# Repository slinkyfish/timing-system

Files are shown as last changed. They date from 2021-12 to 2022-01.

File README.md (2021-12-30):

# timing-system
Components for a micromouse and line follower contest timing system.

Initial development will be related to a drag race timer. 

The contest is described here: https://ukmars.org/contests/drag-race/

And the rules are here: https://ukmars.org/contests/contest-rules/drag-race/

The `legacy` folder contains design files for the existing equipment used in UK contests at Birmingham City University and originally designed by Tony Wilcox.

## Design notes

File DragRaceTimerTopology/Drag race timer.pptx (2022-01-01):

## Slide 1

Drag race timer.pptx

Drag race timer - System block diagram

RATS PC

Power

Signals

Control box

End gantry 1

Lane 1 timer &
6 character display

Start LEDs

Lane 2 timer &
6 character display

Start LEDs

End gantry 2

End gate board

Start gantry 2

End gate board

LED

LED

Start gantry 1

Start gate board

Crossed start LED

Crossed start LED

Start gate board

LED

LED

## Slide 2

Gate processor board components & interfaces

Option to power beam LED from battery when not using gantry

switch

Timer /counter board

Beam state
Seen/Not Seen
High when beam broken or not seen

switch

Micro

Power on LED

5V
Gnd

Beam detector

Beam LED and current limiting resistor

Sensitivity adjuster

Beam not seen indicator LED and current limiting resistor
= Start crossed indicator

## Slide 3

Timer /counter board components and interfaces

12 V DC supply
or battery

2 Push buttons

LED driver 1

LED driver 2

LED driver 3

Gate sensor board 1

Beam state
Seen/Not Seen
High when beam broken or not seen

5V
Gnd

On/off switch

5V reg

Timer Micro processor

Mode selection switches

High - trigger the start light sequence

Gate sensor board 2

Beam state
Seen/Not Seen
High when beam broken or not seen

5V
Gnd

High - All lights out. start timer

Start lights board – This could be incorporated onto the timer/counter board or on a separate board on the end gantry

Serial time data

Arm/ Start

Gnd

5V

Control board

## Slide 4

Control board components & interfaces

ARM
START
RESET
OTHER

Push buttons

Mode switches

Timer Counter board 1

Serial data 1

State display
LEDS

Arm/Start 1

Arm/Start 1

Timer Counter board 2

5V

5V

Serial data 2

Gnd

Micro processor

LEDS

Timer 1 connected

Arm/Start 2

Timer 2 connected

RATS connected

5V

Gnd

USB data link

From 5v supply inputs

RATS PC

Board gets 5v power from either timer/counter board or the USB cable whichever is connected

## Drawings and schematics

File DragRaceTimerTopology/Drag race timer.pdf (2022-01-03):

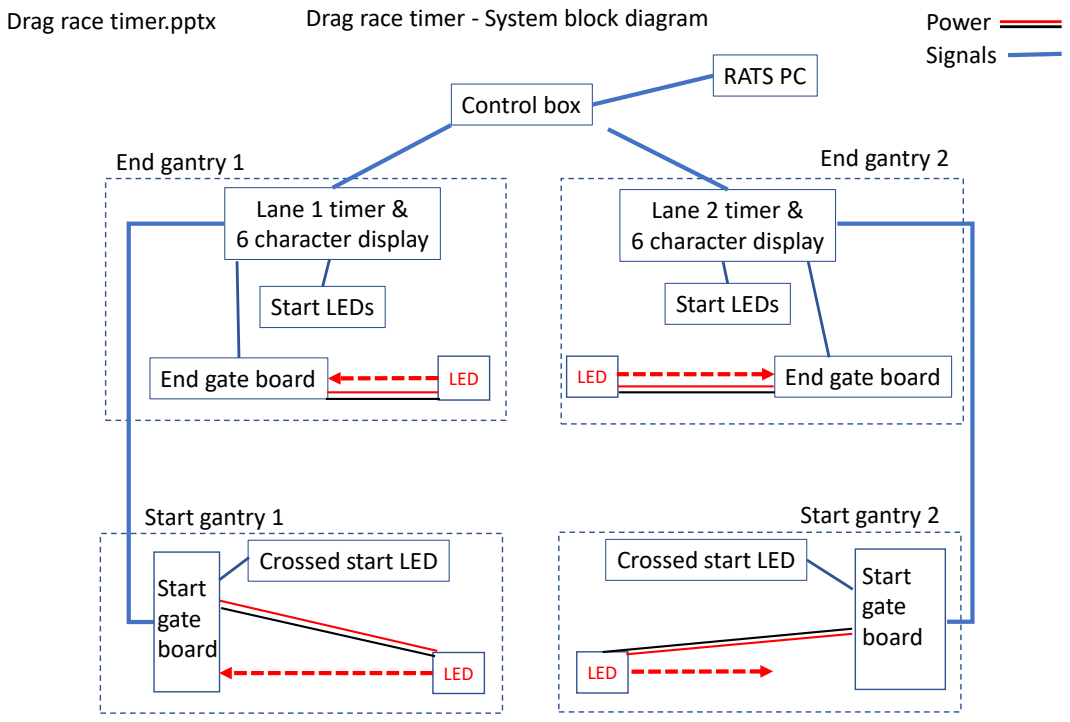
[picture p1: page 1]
Lane 1 timer & 6 character display; Control box; End gate board; LED; Lane 2 timer & 6 character display; Crossed start LED; RATS PC; End gantry 1; End gantry 2; Start gantry 1; Start gantry 2; Power Signals; Start LEDs; Start gate board

Drag race timer.pptx

Drag race timer - System block diagram

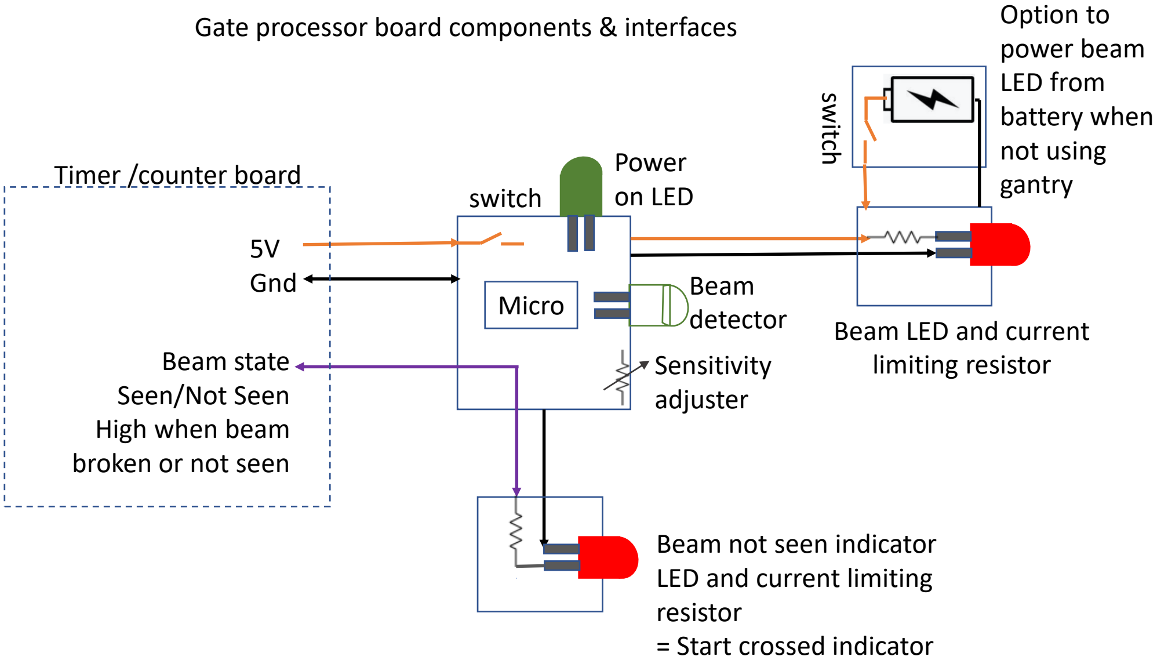
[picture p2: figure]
5V Gnd; Beam state Seen/Not Seen High when beam broken or not seen; Beam not seen indicator LED and current limiting resistor = Start crossed indicator; Beam LED and current limiting resistor; Power; switch; on LED; Timer /counter board; Beam detector; Sensitivity adjuster; Option to power beam LED from battery when not using gantry; Micro

Gate processor board components & interfaces

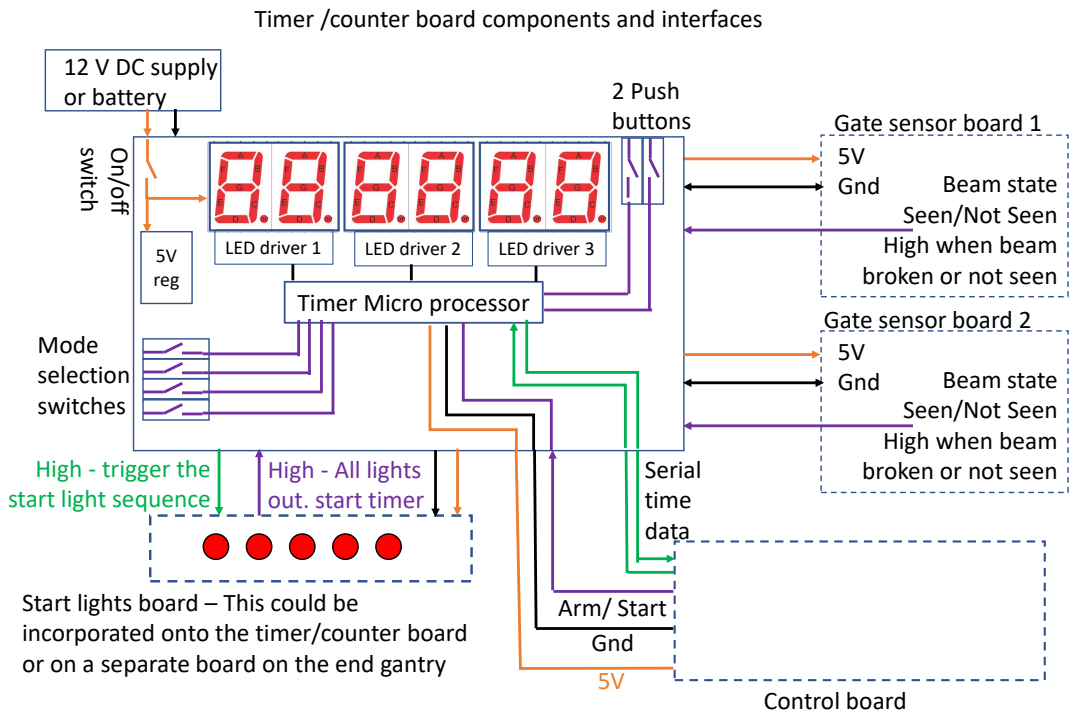
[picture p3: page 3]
Gnd; Beam state; LED driver 1; LED driver 2; LED driver 3; 5V reg; Mode selection switches; Control board; Arm/ Start; 2 Push buttons; Serial time data

Timer /counter board components and interfaces

12 V DC supply
or battery switch On/off

Gate sensor board 1
Seen/Not Seen
High when beam
broken or not seen
Gate sensor board 2

Timer Micro processor

High - trigger the
start light sequence

High - All lights
out. start timer

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

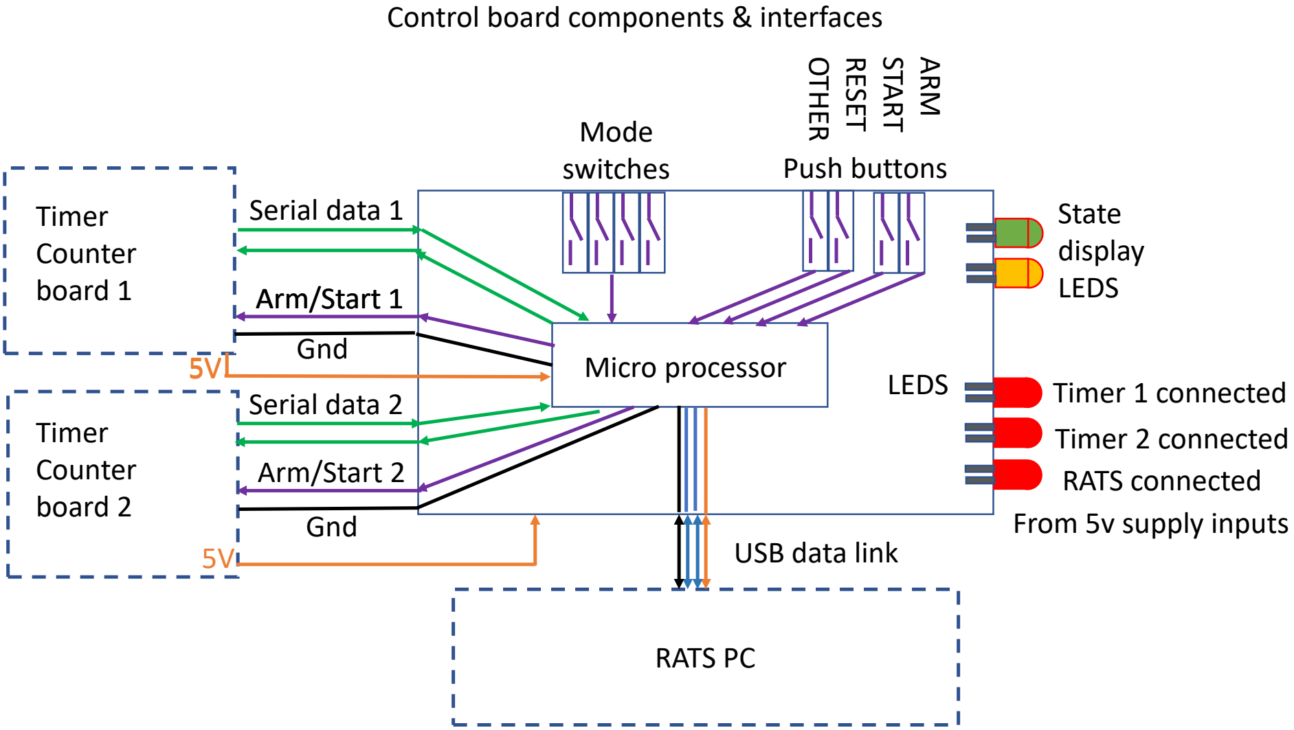
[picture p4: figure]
Control board components & interfaces; Timer Counter board 1; Timer Counter board 2; Serial data 1; Serial data 2; Arm/Start 1; Arm/Start 2; Push buttons; RATS PC; USB data link; Micro processor Gnd; Gnd; LEDS; Mode switches; RATS connected; Timer 1 connected Timer 2 connected; OTHER; RESET; START; ARM; State display LEDS; From 5v supply inputs

Board gets 5v power from either timer/counter board or the USB cable whichever is connected

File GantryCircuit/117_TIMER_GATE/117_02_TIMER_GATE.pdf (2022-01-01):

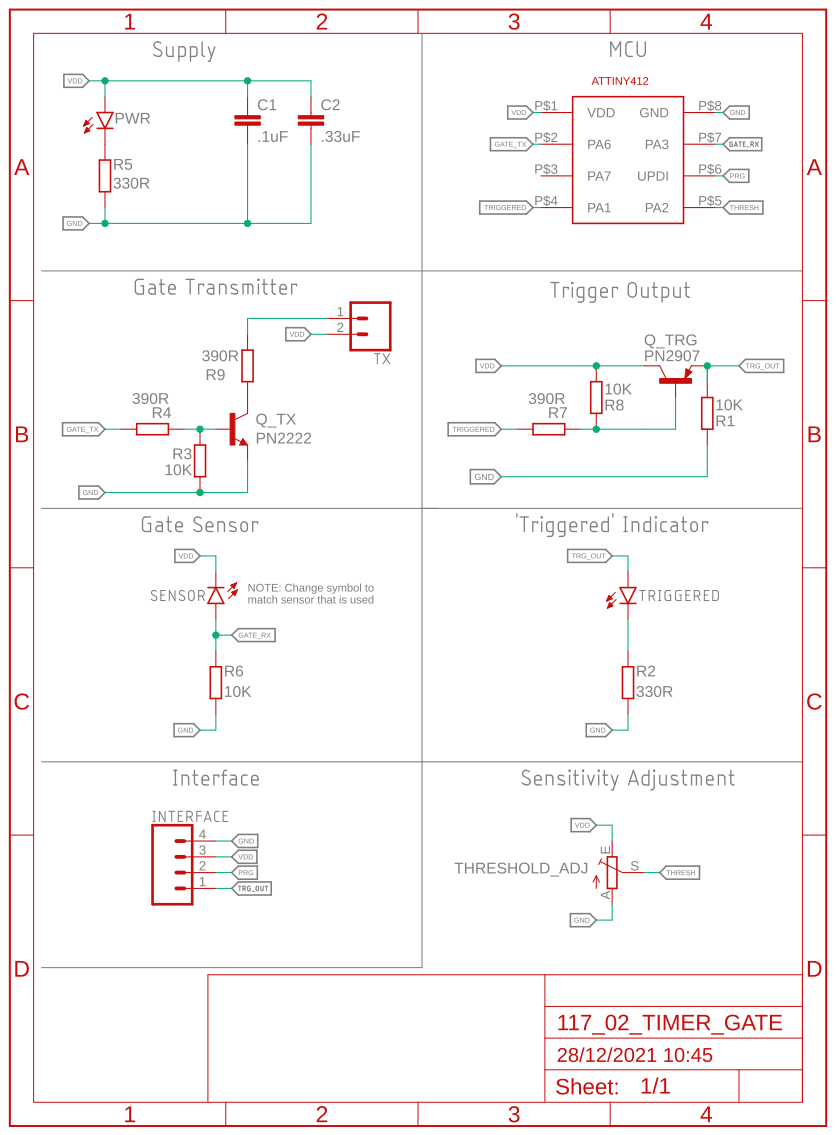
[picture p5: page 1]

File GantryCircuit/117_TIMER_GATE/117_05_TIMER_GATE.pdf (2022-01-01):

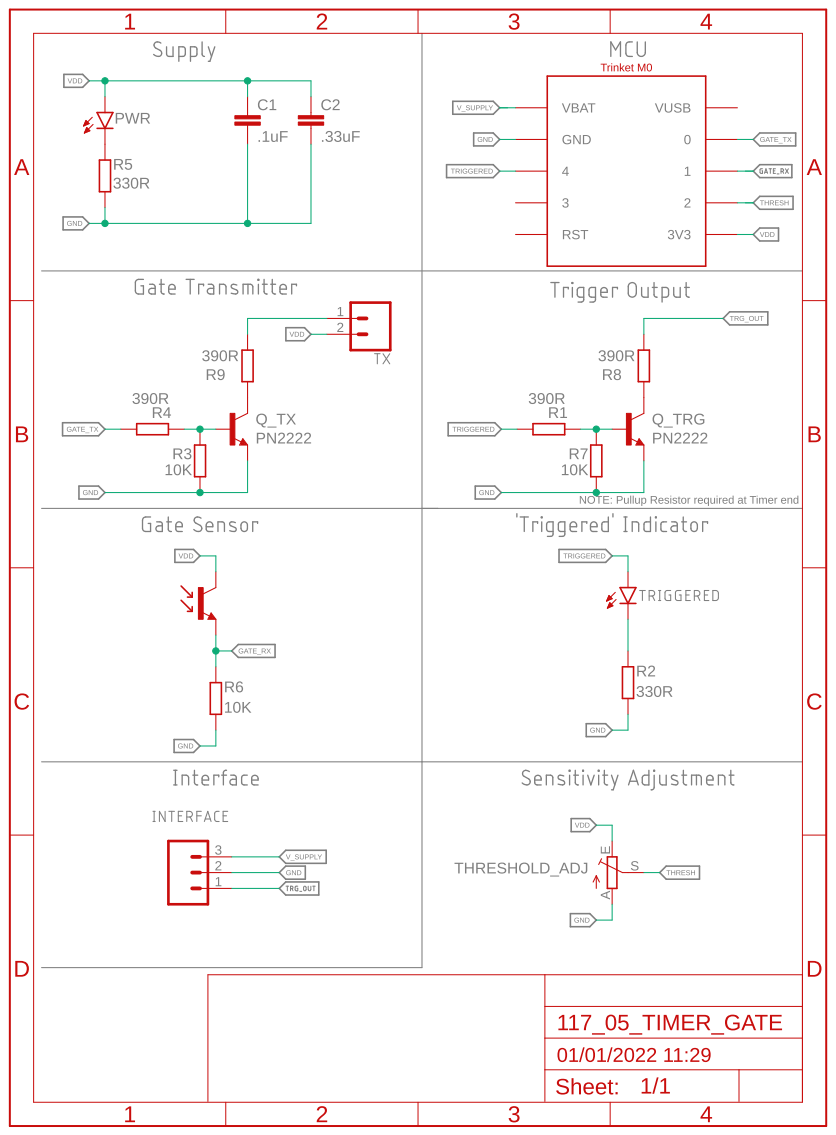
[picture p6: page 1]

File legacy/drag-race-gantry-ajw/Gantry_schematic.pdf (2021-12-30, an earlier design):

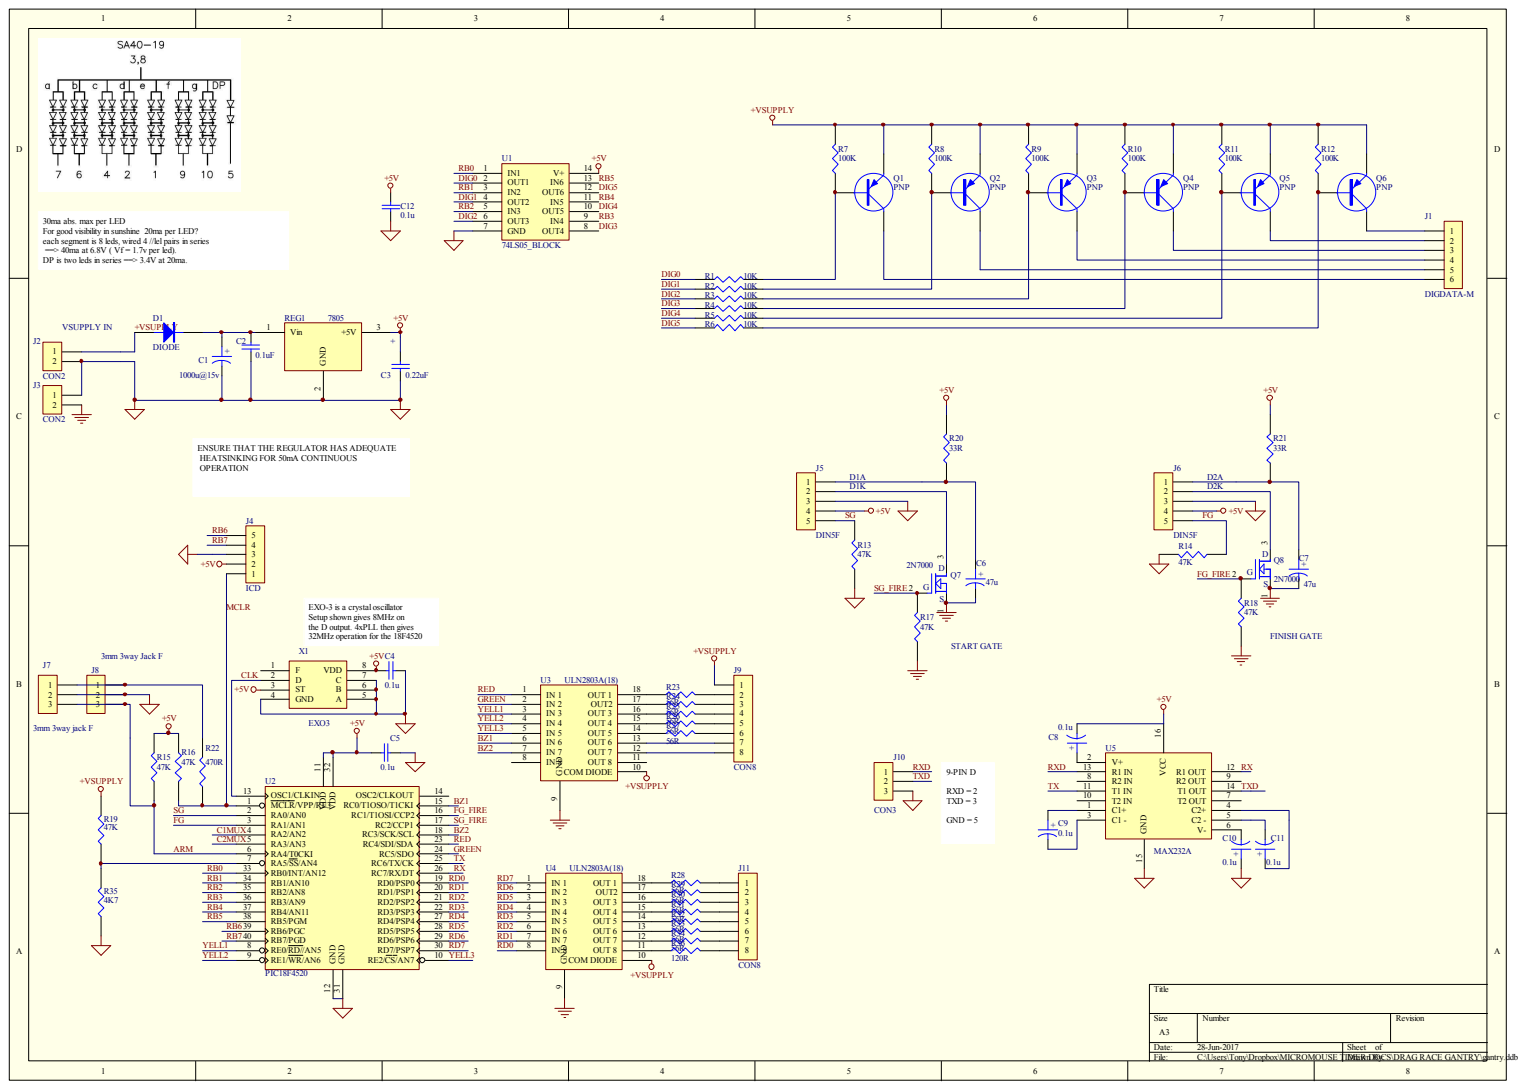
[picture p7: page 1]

30ma abs. max per LED
For good visibility in sunshine 20ma per LED?
each segment is 8 leds, wired 4 //lel pairs in series
==> 40ma at 6.8V ( Vf = 1.7v per led).
DP is two leds in series ==> 3.4V at 20ma.

ENSURE THAT THE REGULATOR HAS ADEQUATE
HEATSINKING FOR 50mA CONTINUOUS
OPERATION

EXO-3 is a crystal oscillator
Setup shown gives 8MHz on
the D output. 4xPLL then gives
32MHz operation for the 18F4520

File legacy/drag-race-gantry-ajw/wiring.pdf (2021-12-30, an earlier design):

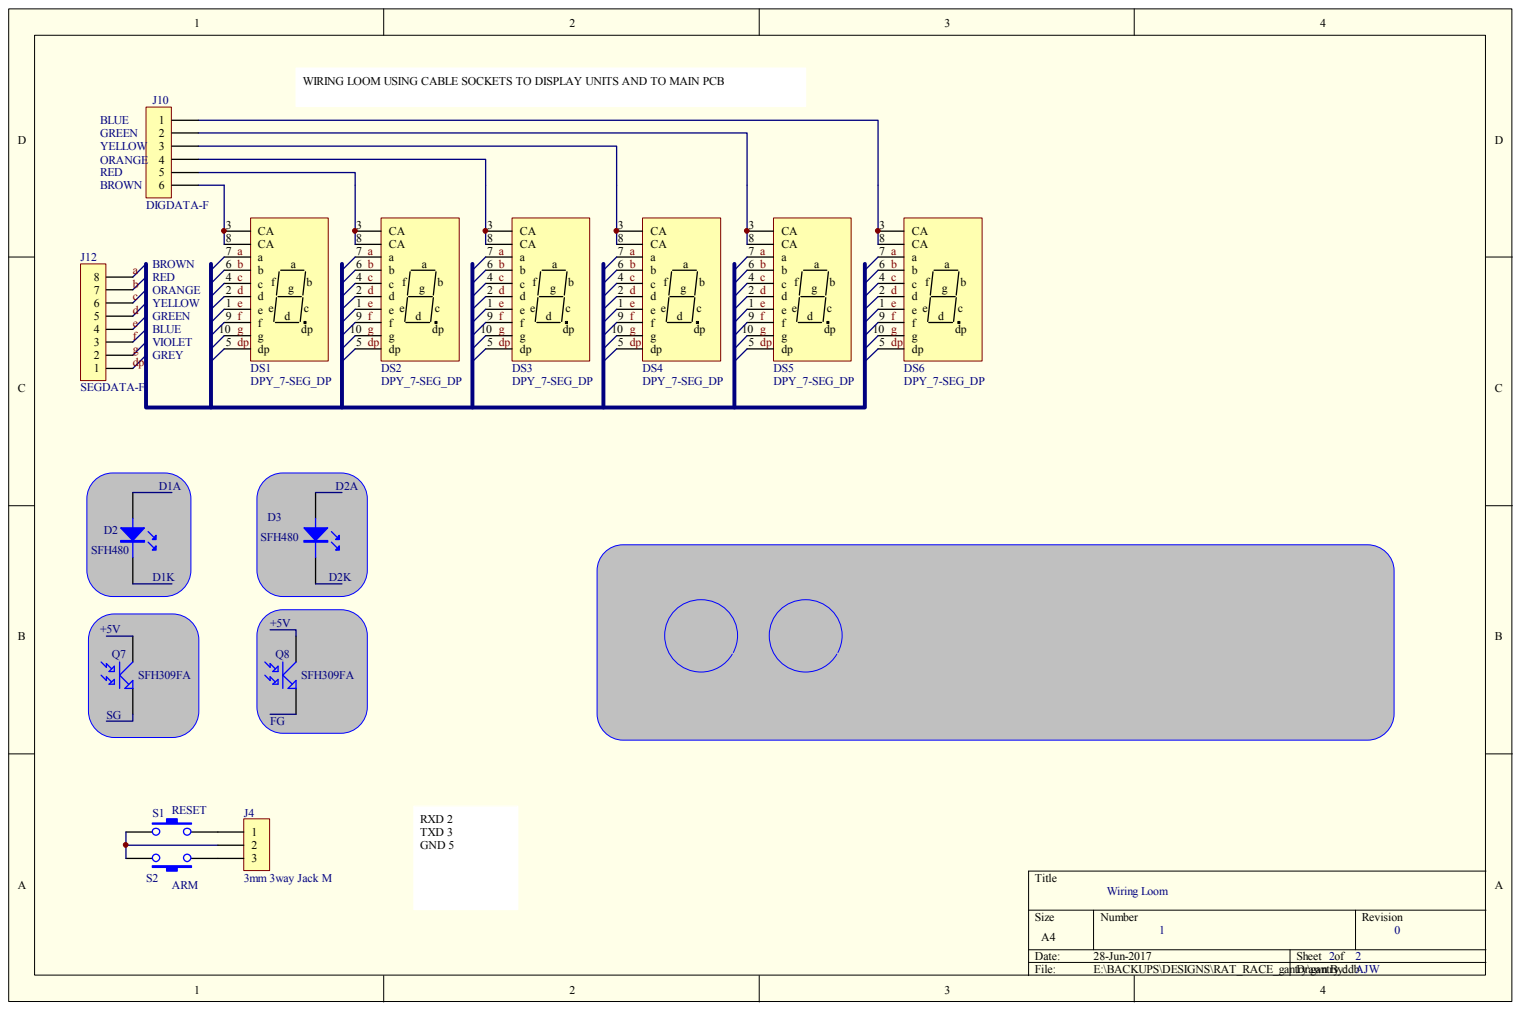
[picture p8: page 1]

WIRING LOOM USING CABLE SOCKETS TO DISPLAY UNITS AND TO MAIN PCB

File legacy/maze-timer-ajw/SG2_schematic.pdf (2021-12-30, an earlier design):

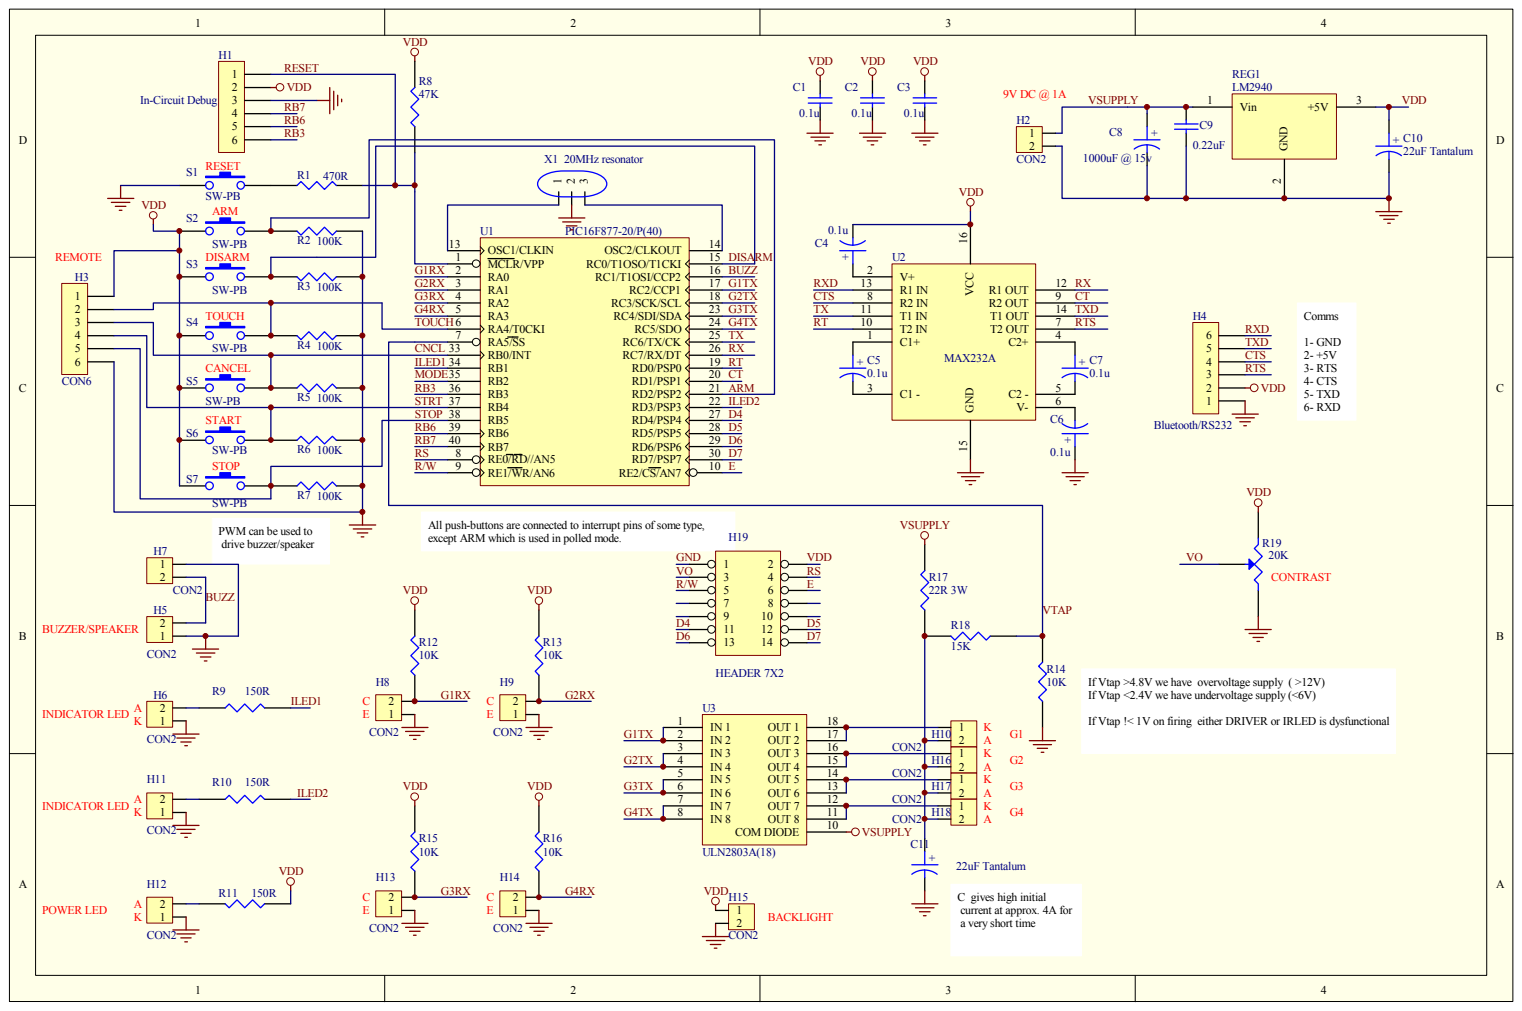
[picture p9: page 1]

PWM can be used to
drive buzzer/speaker

All push-buttons are connected to interrupt pins of some type,
except ARM which is used in polled mode.

If Vtap >4.8V we have overvoltage supply ( >12V)
If Vtap <2.4V we have undervoltage supply (<6V)

If Vtap !< 1V on firing either DRIVER or IRLED is dysfunctional

C gives high initial
current at approx. 4A for
a very short time

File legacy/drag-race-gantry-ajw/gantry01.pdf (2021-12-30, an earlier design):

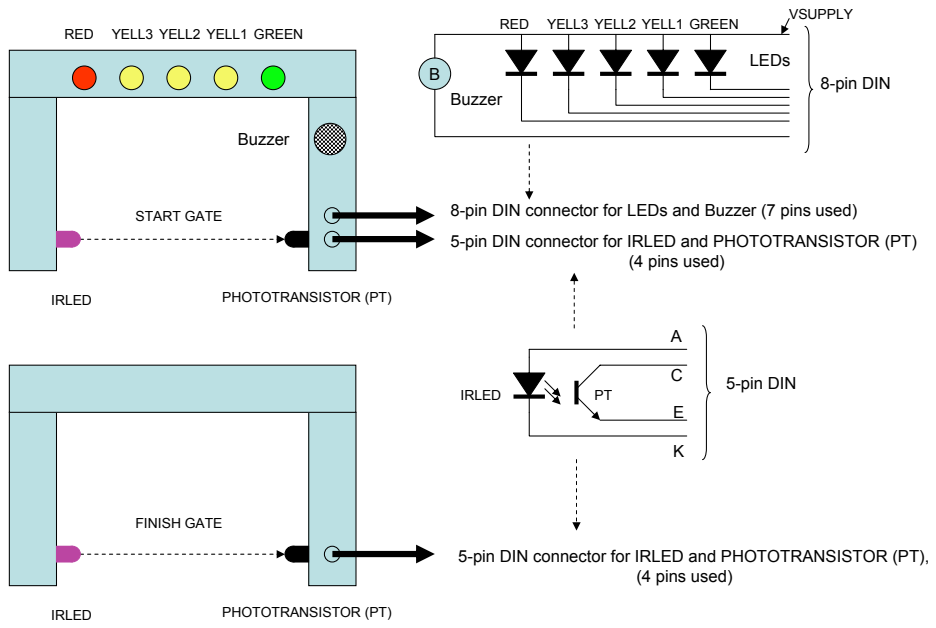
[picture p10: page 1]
(4 pins used); Buzzer; LEDs; 8-pin DIN; 5-pin DIN; RED YELL3 YELL2 YELL1 GREEN; VSUPPLY; IRLED; PHOTOTRANSISTOR (PT); START GATE; FINISH GATE

8-pin DIN connector for LEDs and Buzzer (7 pins used)
5-pin DIN connector for IRLED and PHOTOTRANSISTOR (PT)

5-pin DIN connector for IRLED and PHOTOTRANSISTOR (PT),

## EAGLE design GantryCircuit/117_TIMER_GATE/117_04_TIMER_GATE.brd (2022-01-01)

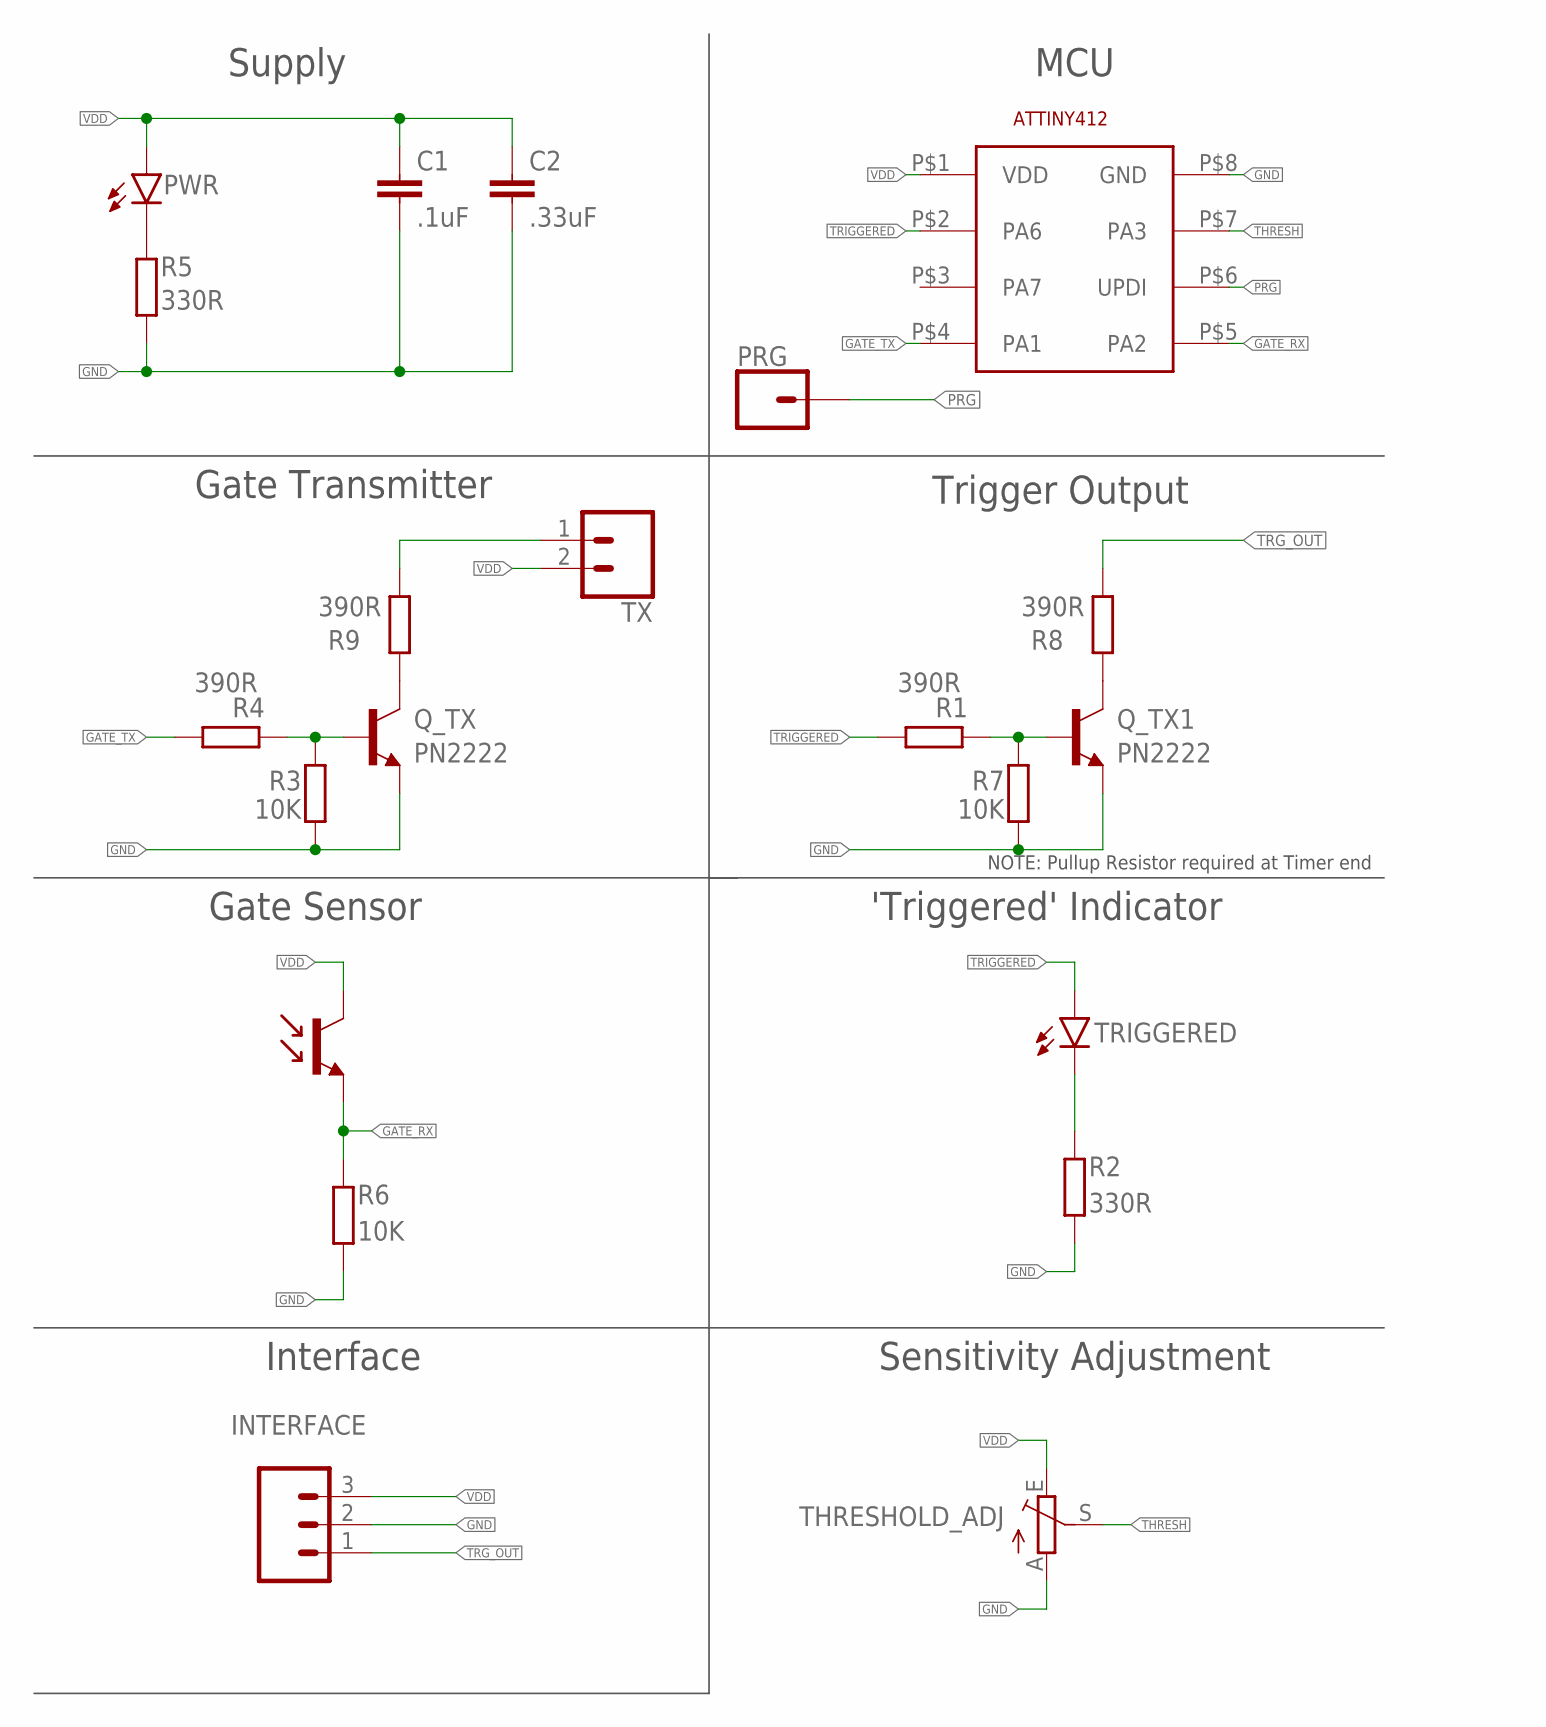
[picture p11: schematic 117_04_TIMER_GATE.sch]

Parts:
C1: .1uF; C0805K
C2: .33uF; C0805K
INTERFACE: CONN_03LONGPADS; 1X03_LONGPADS
PRG: CONN_01PTH_LONGPAD; 1X01_LONGPAD
PWR: LEDSML0805; SML0805
Q_TX, Q_TX1: PN2222; TO92-EBC
R1, R4, R8, R9: 390R; M0805
R2, R5: 330R; M0805
R3, R6, R7: 10K; M0805
THRESHOLD_ADJ: TRIM_EU-S64W; S64W
TRIGGERED: LED5MM; LED_5MM
TX: CONN_02PTH3; 1X02_LONGPADS
U$1: ATTINY412
U$2: PHOTOTRANSISTOR; LED_5MM

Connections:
GATE_RX: R6.2, U$1.P$5 (PA2), U$2.K (E)
GATE_TX: R4.2, U$1.P$4 (PA1)
GND: C1.2, C2.2, INTERFACE.2, Q_TX.E, Q_TX1.E, R2.1, R3.2, R5.1, R6.1, R7.2, THRESHOLD_ADJ.A, U$1.P$8 (GND)
unnamed: PWR.C, R5.2
unnamed: R9.1, TX.1
unnamed: Q_TX1.B, R1.1, R7.1
unnamed: Q_TX.B, R3.1, R4.1
unnamed: Q_TX.C, R9.2
unnamed: Q_TX1.C, R8.2
unnamed: R2.2, TRIGGERED.K (C)
PRG: PRG.1, U$1.P$6 (UPDI)
THRESH: THRESHOLD_ADJ.S, U$1.P$7 (PA3)
TRG_OUT: INTERFACE.1, R8.1
TRIGGERED: R1.2, TRIGGERED.A, U$1.P$2 (PA6)
VDD: C1.1, C2.1, INTERFACE.3, PWR.A, THRESHOLD_ADJ.E, TX.2, U$1.P$1 (VDD), U$2.A (C)

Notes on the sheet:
Gate Sensor
'Triggered' Indicator
Sensitivity Adjustment
Supply
MCU
Gate Transmitter
Interface
Trigger Output
NOTE: Pullup Resistor required at Timer end

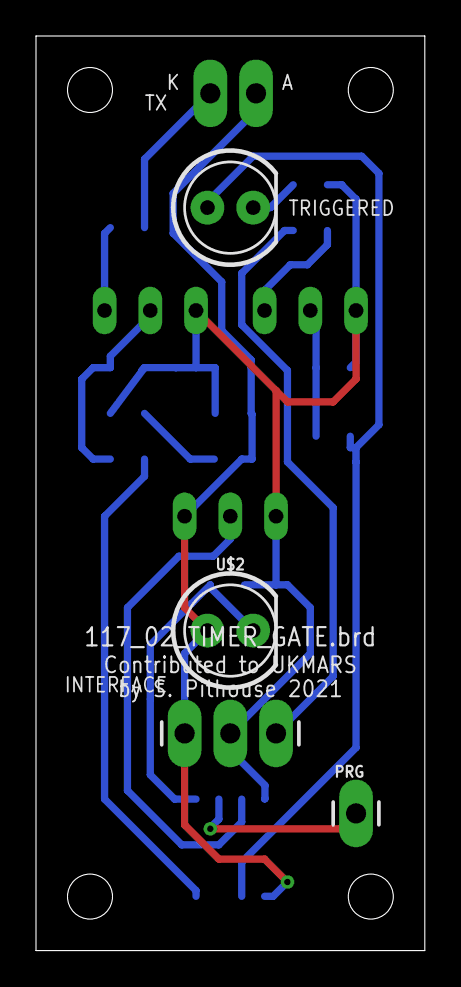
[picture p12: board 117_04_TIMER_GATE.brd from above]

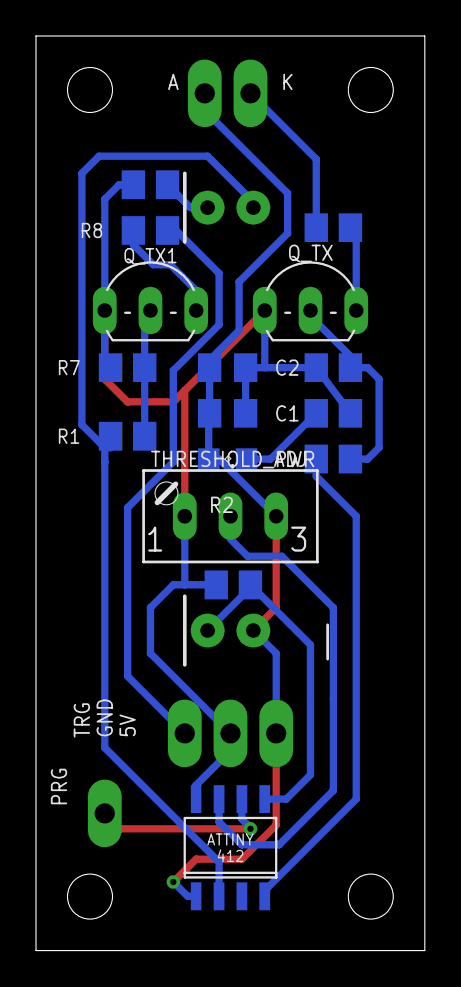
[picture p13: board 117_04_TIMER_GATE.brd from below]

Board: 2 copper layers, 21.6 x 50.8 mm, 21 parts (16 on the bottom side), 15 nets.

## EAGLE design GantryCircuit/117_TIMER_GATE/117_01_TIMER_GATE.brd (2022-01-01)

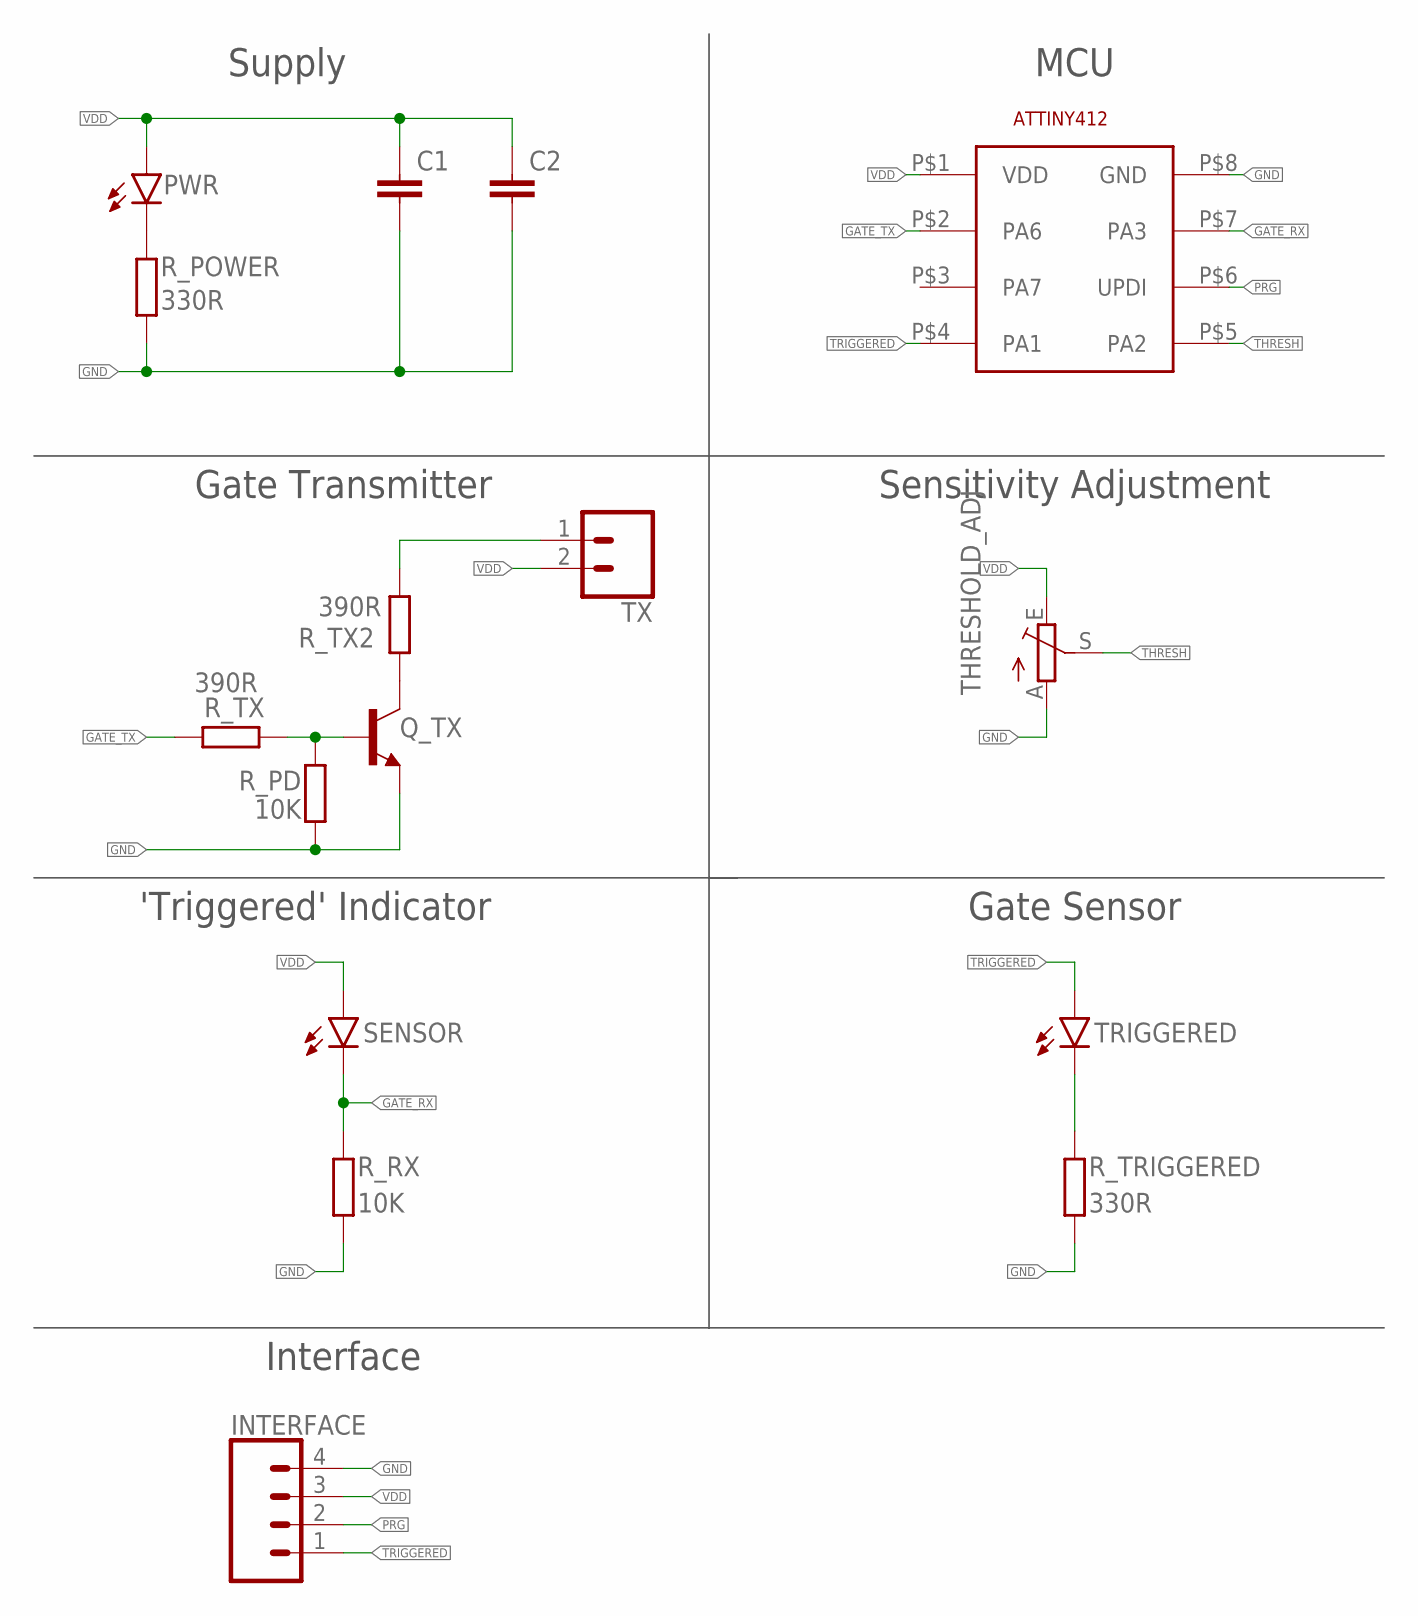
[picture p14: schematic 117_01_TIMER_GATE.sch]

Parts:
C1, C2: C-EUC0805K; C0805K
INTERFACE: CONN_04LONGPADS; 1X04_LONGPADS
PWR: LEDSML0805; SML0805
Q_TX: 2N2222-NPN-TO92-EBC; TO92-EBC
R_PD: 10K; M0805
R_POWER: 330R; M0805
R_RX: 10K; M0805
R_TRIGGERED: 330R; M0805
R_TX, R_TX2: 390R; M0805
SENSOR: LED5MM; LED_5MM
THRESHOLD_ADJ: TRIM_EU-S64W; S64W
TRIGGERED: LED5MM; LED_5MM
TX: CONN_02PTH3; 1X02_LONGPADS
U$1: ATTINY412

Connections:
GATE_RX: R_RX.2, SENSOR.K (C), U$1.P$7 (PA3)
GATE_TX: R_TX.2, U$1.P$2 (PA6)
GND: C1.2, C2.2, INTERFACE.4, Q_TX.E, R_PD.2, R_POWER.1, R_RX.1, R_TRIGGERED.1, THRESHOLD_ADJ.A, U$1.P$8 (GND)
unnamed: PWR.C, R_POWER.2
unnamed: R_TX2.1, TX.1
unnamed: Q_TX.B, R_PD.1, R_TX.1
unnamed: Q_TX.C, R_TX2.2
unnamed: R_TRIGGERED.2, TRIGGERED.K (C)
PRG: INTERFACE.2, U$1.P$6 (UPDI)
THRESH: THRESHOLD_ADJ.S, U$1.P$5 (PA2)
TRIGGERED: INTERFACE.1, TRIGGERED.A, U$1.P$4 (PA1)
VDD: C1.1, C2.1, INTERFACE.3, PWR.A, SENSOR.A, THRESHOLD_ADJ.E, TX.2, U$1.P$1 (VDD)

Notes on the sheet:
Gate Sensor
'Triggered' Indicator
Sensitivity Adjustment
Supply
MCU
Gate Transmitter
Interface

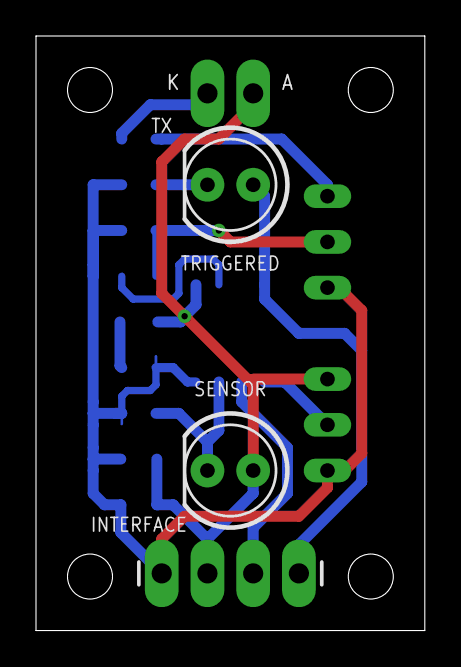
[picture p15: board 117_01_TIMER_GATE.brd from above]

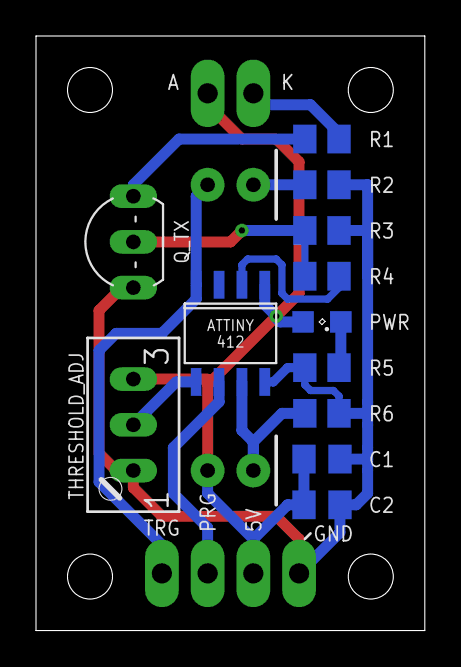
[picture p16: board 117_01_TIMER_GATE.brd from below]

Board: 2 copper layers, 21.6 x 33.0 mm, 16 parts (12 on the bottom side), 12 nets.

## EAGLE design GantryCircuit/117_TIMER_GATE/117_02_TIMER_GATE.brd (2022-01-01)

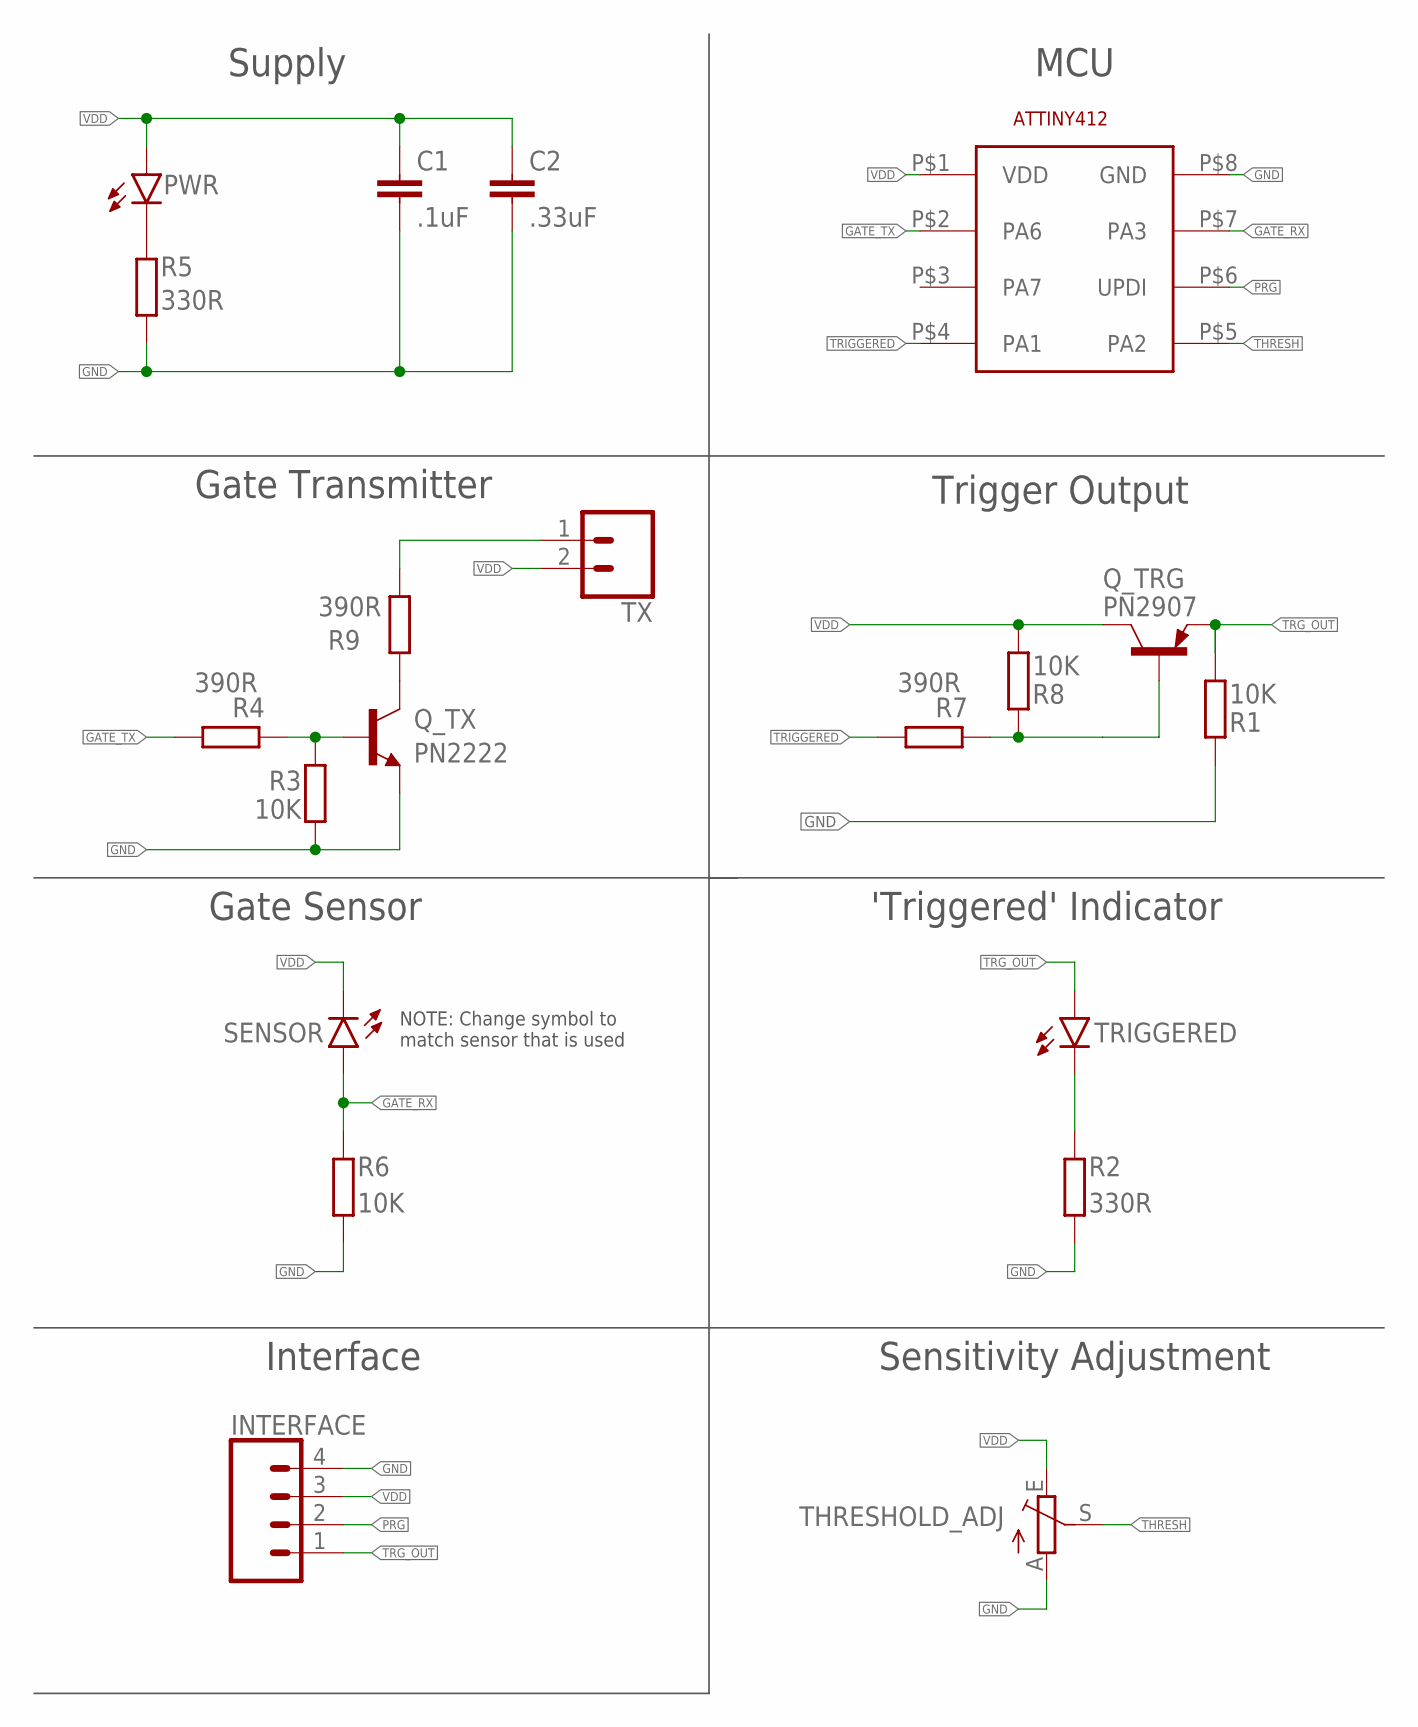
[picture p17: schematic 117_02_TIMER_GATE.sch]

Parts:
C1: .1uF; C0805K
C2: .33uF; C0805K
INTERFACE: CONN_04LONGPADS; 1X04_LONGPADS
PWR: LEDSML0805; SML0805
Q_TRG: PN2907; TO92-CBE
Q_TX: PN2222; TO92-EBC
R1, R3, R6, R8: 10K; M0805
R2, R5: 330R; M0805
R4, R7, R9: 390R; M0805
SENSOR: LED5MM; LED_5MM
THRESHOLD_ADJ: TRIM_EU-S64W; S64W
TRIGGERED: LED5MM; LED_5MM
TX: CONN_02PTH3; 1X02_LONGPADS
U$1: ATTINY412

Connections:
GATE_RX: R6.2, SENSOR.A, U$1.P$7 (PA3)
GATE_TX: R4.2, U$1.P$2 (PA6)
GND: C1.2, C2.2, INTERFACE.4, Q_TX.E, R1.1, R2.1, R3.2, R5.1, R6.1, THRESHOLD_ADJ.A, U$1.P$8 (GND)
unnamed: PWR.C, R5.2
unnamed: R9.1, TX.1
unnamed: Q_TX.B, R3.1, R4.1
unnamed: Q_TX.C, R9.2
unnamed: R2.2, TRIGGERED.K (C)
PRG: INTERFACE.2, U$1.P$6 (UPDI)
THRESH: THRESHOLD_ADJ.S, U$1.P$5 (PA2)
TRG_BASE: Q_TRG.B, R7.1, R8.1
TRG_OUT: INTERFACE.1, Q_TRG.E, R1.2, TRIGGERED.A
TRIGGERED: R7.2, U$1.P$4 (PA1)
VDD: C1.1, C2.1, INTERFACE.3, PWR.A, Q_TRG.C, R8.2, SENSOR.K (C), THRESHOLD_ADJ.E, TX.2, U$1.P$1 (VDD)

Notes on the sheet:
Gate Sensor
'Triggered' Indicator
Sensitivity Adjustment
Supply
MCU
Gate Transmitter
Interface
Trigger Output
NOTE: Change symbol to match sensor that is used

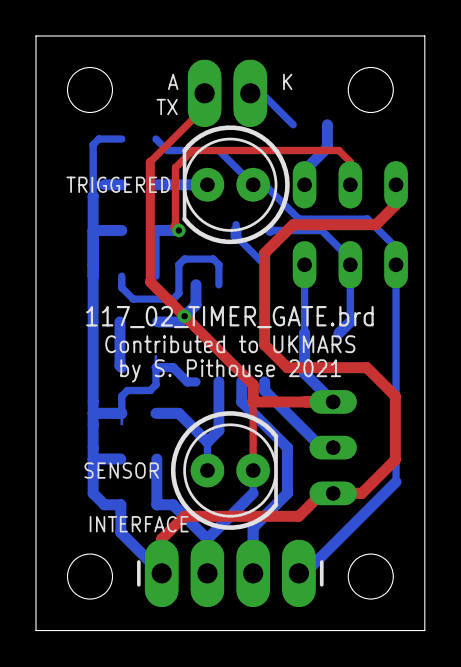
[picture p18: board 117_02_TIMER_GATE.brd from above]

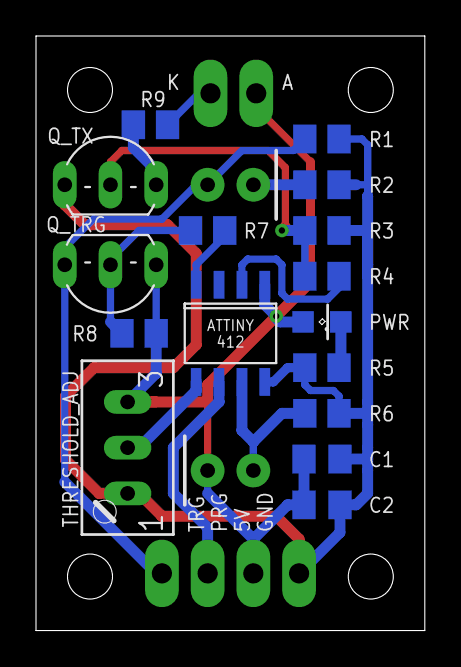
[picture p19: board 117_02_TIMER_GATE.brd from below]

Board: 2 copper layers, 21.6 x 33.0 mm, 20 parts (16 on the bottom side), 14 nets.

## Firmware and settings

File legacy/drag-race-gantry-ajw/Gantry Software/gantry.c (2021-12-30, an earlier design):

// AJW 28/06/07 Gantry timer
// 19/6/07 Added comms at 115200
//
// 19/06/07 added startgate: comparators used.


#include <p18f4520.h>
#include "gantry.h"
#include <timers.h>
#include <usart.h>

#pragma config OSC=HSPLL,PWRT=ON,WDT=OFF,BOREN=OFF,MCLRE=ON,PBADEN=OFF
#pragma config CCP2MX=PORTC,STVREN=ON,LVP=OFF,XINST=OFF,DEBUG=ON

typedef struct {
  unsigned char val0;
  unsigned char val1;
  unsigned char val2;
  unsigned char val3;
  unsigned char val4;
  unsigned char val5;
}  display_buffer ;

static display_buffer dbuf;
static unsigned char TIMER = FALSE, state = 0, SGTRIG = FALSE, FGTRIG = FALSE, FALSE_START = FALSE;
const char seg7[] = {zero, one, two, three, four, five, six, seven, eight, nine, blank};

static unsigned int secs = 0, millisecs = 0, timeout = 0, beeptimer = 0;

/********************* INTERRUPT initialisation ****************************/
void ISR_HI(void);
void ISR_LO(void);
void init_interrupts(void);
void init_cmp(void);
void refresh_display(void);
void update_time(void);
void init_ports(void);
void fsm(void);
void zero_time(void);
void beep(unsigned int);
/*-----------------------------------------------------------------------*/
/* This bit is to initialise the interrupt vectors
/*-----------------------------------------------------------------------*/
#pragma code high_vector_section=0x8  // goto absolute code section
void high_vector(void) {
  _asm GOTO ISR_HI _endasm
}

#pragma code low_vector_section=0x18  // goto absolute code section
void low_vector(void) {
  _asm GOTO ISR_LO _endasm
}

#pragma code   // return to normal code section

/*********************   INTERRUPT routines    ****************************/

/*-----------------------------------------------------------------------*/
/* High level interrupt routine  */
/*-----------------------------------------------------------------------*/
#pragma interrupt ISR_HI
void ISR_HI(void) {
  static unsigned char lastCOUT1 = 0, lastCOUT2 = 0, currentCOUT1 = 0, currentCOUT2 = 0, intcount = 0, dspcount = 0;

  if (PIR1bits.TMR1IF & PIE1bits.TMR1IE) {  // timer 1 is master 1ms timer
    PIR1bits.TMR1IF = 0;
    WriteTimer1(T1CONST);

    SGTX = FGTX = 1; //irleds on
    // use clock/display update as the IRLED setup time
    update_time();
    if (TIMER) {
      if (millisecs++ >= 999) {
        millisecs = 0;
        if (secs++ >= 999) {
          secs = 0;
        }
      }
    }
    if (dspcount++ > 1) {
      dspcount = 0;
      refresh_display();
    }
    // Read Start Gate comparator and set/clear flag
    if (SGRX) {
      SGTRIG = TRUE;  // SG = Start Gate
    } else {
      SGTRIG = FALSE;
    }
    // Read Finish Gate comparator and set/clear flag
    if (FGRX) {
      FGTRIG = TRUE;  // FG = Finish Gate
    } else {
      FGTRIG = FALSE;
    }
    SGTX = FGTX = 0; 	//irleds off
    if (timeout > 0) {
      timeout --;  // countdown
    }
    fsm();				// do state machine
    if (beeptimer > 0) {
      beeptimer --;
      BUZZ1 = TRUE;
    } else {
      BUZZ1 = FALSE;
    }
  }
}
/*-----------------------------------------------------------------------*/
/* low priority interrupt routine  */
/*-----------------------------------------------------------------------*/
#pragma interruptlow ISR_LO
void
ISR_LO(void) {

}

/*********************      MAIN     ****************************/




void main(void) {


  unsigned  int i = 0;

  init_ports();
  init_interrupts();
  init_cmp();
  state = 0;
  WriteTimer1(T1CONST);
  OpenTimer1(TIMER_INT_ON &
             T1_16BIT_RW &
             T1_SOURCE_INT &
             T1_PS_1_1 &
             T1_OSC1EN_OFF &
             T1_SYNC_EXT_OFF);

  OpenUSART(USART_TX_INT_OFF  &
            USART_RX_INT_OFF  &
            USART_ASYNCH_MODE &
            USART_EIGHT_BIT   &
            USART_CONT_RX &
            USART_BRGH_HIGH, 51); //38400 from 32MHz

  while (1) {

  }
}

void init_interrupts(void) {
  /* Enable interrupt priority */
  RCONbits.IPEN = 1;

  /* SET timer1 INTERRUPT PRIORITY and enable*/
  IPR1bits.TMR1IP = 1;
  PIE1bits.TMR1IE = 1;
  INTCONbits.GIEH = 1;
  INTCONbits.GIEL = 1;
}

void init_cmp(void) {
  ADCON1 = 10;
  CMCON = 0x06; // only mode with common CVREF
  CVRCON = 12; // SET TO 2.5V
  CVRCONbits.CVREN = 1;  // comparator on
  CVRCONbits.CVROE = 0;  //
  CVRCONbits.CVRR = 1;
  CVRCONbits.CVRSS = 0;
}

void refresh_display(void) {
  static unsigned char dignum = 0;

  switch (dignum) {
    case 0:
      digsel = dig0;
      dignum ++;
      digdata = seg7[dbuf.val0];
      dp = 0;
      break;
    case 1:
      digsel = dig1;
      dignum ++;
      digdata = seg7[dbuf.val1];
      dp = 0;
      break;
    case 2:
      digsel = dig2;
      dignum ++;
      digdata = seg7[dbuf.val2];
      dp = 0;
      break;
    case 3:
      digsel = dig3;
      dignum ++;
      digdata = seg7[dbuf.val3];
      dp = 1;
      break;
    case 4:
      digsel = dig4;
      dignum ++;
      digdata = seg7[dbuf.val4];
      dp = 0;
      break;
    case 5:
      digsel = dig5;
      dignum = 0;
      //digdata = seg7[dbuf.val5];
      if (FALSE_START) {
        digdata = 0x71;  // F for false
      } else {
        digdata = blank;
      }
      dp = 0;

      break;
  }
}

void update_time(void) {
  dbuf.val0 = millisecs % 10;
  dbuf.val1 = (millisecs / 10) % 10;
  dbuf.val2 = millisecs / 100;
  dbuf.val3 = secs % 10;
  dbuf.val4 = (secs / 10) % 10;
  dbuf.val5 = secs / 100;
}

void zero_time(void) {
  millisecs = 0;
  secs = 0;
}

void init_ports(void) {
  TRISB = 0xc0; 			// bottom 5 outputs  for digit select
  LATB = 0;				// all segments off
  TRISD = 0; 			// all outputs  for segment select i.e. data
  LATD = 0x3f;			// all digits off
  TRISA = 0xff;          // all inputs

  TRISCbits.TRISC3 = 0;	// BUZZ2
  BUZZ2 = 0;
  TRISCbits.TRISC2 = 0;	// SGTX
  SGTX = 0;
  TRISCbits.TRISC1 = 0;	// FGTX
  FGTX = 0;
  TRISCbits.TRISC0 = 0;	// BUZZ1
  BUZZ1 = 0;
  TRISCbits.TRISC5 = 0;	// GREEN led
  GREEN = 0;
  TRISCbits.TRISC4 = 0;	// RED led
  RED = 0;
  TRISEbits.TRISE0 = 0;	// YELL1
  YELL1 = 0;
  TRISEbits.TRISE1 = 0;	// YELL2
  YELL1 = 0;
  TRISEbits.TRISE2 = 0;	// YELL3
  YELL1 = 0;
}

void fsm(void) {
  switch (state) {
    case 0:
      YELL3 = YELL2 = YELL1 = RED = GREEN = FALSE;

      if (SGTRIG) {
        RED = TRUE;
      } else {
        RED = FALSE;
      }
      if (ARM == 0) {
        state = 8;
        timeout = 1000;  //1 second timeout
        zero_time();
        FALSE_START = FALSE;
        beep(250);
      }
      break;
    case 8:
      if (SGTRIG) {
        RED = TRUE;
      } else {
        RED = FALSE;
      }

      if ((ARM == 0) && (timeout == 0)) {
        state = 1;
        timeout = 3000;  //1 second timeout
        beep(1000);
      }
      break;


    case 1:
      if (SGTRIG) {
        RED = TRUE;   // RED doesn't clear - FALSE START
        FALSE_START = TRUE;
      }
      if (timeout == 0) {
        YELL3 = YELL2 = YELL1 = TRUE;
        timeout = 1000;
        state = 2;
      }
      break;
    case 2:
      if (SGTRIG) {
        RED = TRUE;   // RED doesn't clear - FALSE START
        FALSE_START = TRUE;
      }
      if (timeout == 0) {
        state = 3;
        timeout = 1000;  //  1 second timeout
        YELL1 = FALSE;
      }
      break;
    case 3:
      if (SGTRIG) {
        RED = TRUE;   // RED doesn't clear - FALSE START
        FALSE_START = TRUE;
      }
      if (timeout == 0) {
        state = 4;
        timeout = 1000;  // 1 second timeout
        YELL2 = FALSE;
      }
      break;
    case 4:
      if (SGTRIG) {
        RED = TRUE;   // RED doesn't clear - FALSE START
        FALSE_START = TRUE;
      }
      if (timeout == 0) {
        state = 5;
        YELL3 = FALSE;
      }
      break;
    case 5:
      if (SGTRIG) {
        RED = TRUE;   // RED doesn't clear - FALSE START
        FALSE_START = TRUE;
      }
      if (timeout == 0) {
        state = 6;
        GREEN = TRUE;
        TIMER = TRUE;
      }
      break;
    case 6:
      if (FGTRIG) {
        TIMER = FALSE;
        state = 7;
      }
      break;
    case 7:
      if (ARM == 0) {
        state = 0;
      }
      break;
  }

}

void beep(unsigned int time) {
  beeptimer = time;
}

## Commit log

2021-12-30 add legacy files
    [GANTRY03.GBL, GANTRY03.GBS, GANTRY03.GKO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]
2022-01-01 Initial Commit
    Gantry Sch and Brd as they stand
    [117_01_TIMER_GATE.brd, 117_01_TIMER_GATE.sch, 117_02_TIMER_GATE.brd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]

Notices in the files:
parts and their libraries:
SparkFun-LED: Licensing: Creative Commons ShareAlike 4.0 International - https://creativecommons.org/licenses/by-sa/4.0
